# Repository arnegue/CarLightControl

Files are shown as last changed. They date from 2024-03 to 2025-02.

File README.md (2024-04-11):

# CarLightControl
Control and dim (dismounted) carlights with an ESP32 webserver, or via potentiometer.

A friend of mine asked me for a small project to control old taillights from his car. Me, happy that i can solder and program again and willing to help, started doing it. Here it is.

## What's in the code
The code controls 5 lights of one backlight of a car:
* Blinker
* Reverse light
* Brake light
* Running light

Each light is individually dimmable. Blinker is able blink (you don't say).

# Circuit
See  [this diagram](#Simplified) for a simplified circuit. I also made a more professional one with EasyEDA which could be ordered there for a few bugs.

## Easy-EDA
Follow link to [OSHWLab](https://oshwlab.com/frostfreak/carlightcontrol):

## Simplified
Following diagram (nice paint skills, eh?) shows a simplified circuit how every bulb (in this case only one) is connected to the ESP32.

* **12 V**: Power Source for dimming/switching/blinking lamps
* **5 V**: Power Source for ESP32 (depends on your development kit!)
* **3.3 V**: Maximum voltage for ESP32 Input from potentiometer
* **IRF9540N**: P-Channel Mosfet to control each bulb
* **BC547**: NPN-Transistor to toggle IRF9540N
* **250 Ohms potentiometer**: for measuring voltage input
* **1K Ohms resistor**: On ESP32 for safeguarding and current limiting
* **10K Ohms resistor**: Pull up resistor

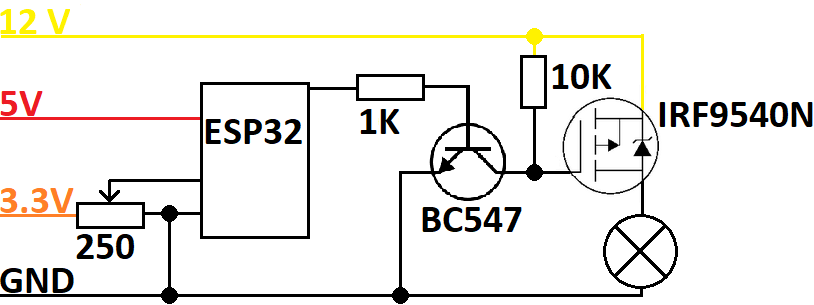
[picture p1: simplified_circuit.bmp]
simplified circuit diagram


Note: I take no guarantee on correctness. I am a programmer, not an electronics engineer ;)

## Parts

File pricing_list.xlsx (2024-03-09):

 | Typ | Name | Anzahl | Einzelpreis | Preis
Platine | Microcontroller | ESP32 WROOM32D | 1 | 8.99 € | 8.99 €
 | Buchse & Stecker | JST 3er | 4 | 0.10 € | 0.40 €
 | Transistor | NPN BC547 | 4 | 0.34 € | 1.36 €
 | Transistor | P-Channel Mosfet IRF9540N | 4 | 0.34 € | 1.36 €
 | Widerstand | Widerstände | 8 | 0.08 € | 0.64 €
 | Buchse & Stecker | JST 2er (Strom) | 1 | 0.10 € | 0.10 €
 | Spannungswandler | MP1584EN | 1 | 1.50 € | 1.50 €
 | Buchse & Stecker | JST 6er (Anschluss zu Lampenbuchse) | 1 | 0.10 € | 0.10 €
 | Kühlkörper | Aluminium Kühlkörper | 4 | 0.36 € | 1.44 €
Gehäusewand | Buchse & Stecker | Lampenbuchse & -Stecker | 1 | 1.50 € | 1.50 €
 | Buchse & Stecker | Strombuchse | 1 | 3.75 € | 3.75 €
 |  | Netzadapter (12V 5A) | 1 | 13.89 € | 13.89 €
Deckel | Potentiometer | Linear Potentiometer 250 Ohm | 4 | 1.78 € | 7.12 €
 | Schalter | Kippschalter 12V | 1 | 2.75 € | 2.75 €
Gehäuse | Gehäuse | ABS Kunststoffgehäuse | 1 | 7.17 € | 7.17 €
 |  |  |  |  | 52.05 €

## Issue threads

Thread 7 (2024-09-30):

Work without WiFi

arnegue, 2024-09-30:
The device won't work without WiFi. That's not necessary

SubFeature:

- Additionally print out own IP when connected
- change hostname

Closed 2025-02-13.

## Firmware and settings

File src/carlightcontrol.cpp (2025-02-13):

#include "wifi_secrets.h"
#include "pwm_switch.hpp"
#include "blinking_pwm_switch.hpp"
#include "switch_web_server.hpp"

#define ENABLE_POTENTIOMETER /* You might want to disable them for testing */

// clang-format off
// Create instances of Lights
//                         Name             PWMPin, PotiPin
PWMSwitch ruecklicht{     "Ruecklicht",     13,     35}; // PWM1
PWMSwitch bremslicht{     "BremsLicht 1",   27,     34}; // PWM2
BlinkingPWMSwitch blinker{"Blinker",        33,     39}; // PWM3
PWMSwitch rueckfahrlicht{ "Bremslicht 2",   32,     36}; // PWM4
// clang-format on

// Add lights to vector
const static std::vector<PWMSwitch *> switches = {
    &ruecklicht,
    &bremslicht,
    &rueckfahrlicht,
    &blinker};

SwitchWebServer web_server(switches, 80);

void CheckWiFiStatus(wl_status_t &previousState)
{
    auto wifiState = WiFiClass::status();
    if (wifiState != WL_CONNECTED)
    {
        Serial.printf("Connecting to WiFi. Current state: %d\n", wifiState);
    }
    else if (wifiState == WL_CONNECTED && previousState != wifiState)
    {
        Serial.printf("Connected to WiFi \"%s\" with IP: ", ssid);
        Serial.println(WiFi.localIP());
        previousState = wifiState;
    }
}

wl_status_t lastWiFiState = WL_DISCONNECTED;

/**
 * @brief Setup routine. Setups Serial, WiFi, Switches and SwitchWebServer
 */
void setup()
{
    Serial.begin(115200);

    // WiFi
    WiFi.begin(ssid, password);
    WiFiClass::setHostname("headlight1");
    CheckWiFiStatus(lastWiFiState);

    // Switches
    for (auto pwm_switch : switches)
    {
        Serial.print("Setting up switch: ");
        Serial.println(pwm_switch->getName());
        pwm_switch->setup();
    }
    Serial.println("Setup switches");

    // Server
    Serial.println("Starting server");
    web_server.begin();
    Serial.println("Started server");
}

/**
 * @brief  Loop which polls wifi state and potentiometer values. If a value changed, override current one (else keep the one either set by previous pwm or from server)
 */
void loop()
{
    CheckWiFiStatus(lastWiFiState);
#ifdef ENABLE_POTENTIOMETER
    for (auto pwm_switch : switches)
    {
        pwm_switch->measurePotentiometerSetValue();
    }
#endif
    delay(100);
}

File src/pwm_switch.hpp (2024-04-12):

#ifndef PWM_SWITCH_H
#define PWM_SWITCH_H

#include <WString.h>
#include <stdint.h>
#include <esp32-hal.h>

/**
 * @brief Class for a PWM-based Switch (Light)
 */
class PWMSwitch
{
public:
    /**
     * @brief Construct a new PWMSwitch object
     *
     * @param pwm_name Name of switch
     * @param pwm_pin Pin to toggle PWM
     * @param potentiometer_pin Pin of potentiometer
     */
    PWMSwitch(const String &pwm_name, uint8_t pwm_pin, uint8_t potentiometer_pin)
        : mName(pwm_name),
          mPWMPin(pwm_pin),
          mPotentiometerPin(potentiometer_pin) {}

    /**
     * @brief Destroy the PWMSwitch object
     */
    virtual ~PWMSwitch() = default;

    /**
     * @brief Return next pwm channel. Only call once per instance!
     *
     * @return next pwm channel
     */
    static uint8_t getNextPWMChannel();

    /**
     * @brief Sets up PWM. Attach timer, set pin and frequencies
     */
    virtual void setup();

    /**
     * @brief Returns name of switch
     *
     * @return Name
     */
    const String &getName() const;

    /**
     * @brief Enables PWM. When switching on, set mDutyCycle to previous set value
     *
     * @param on Boolean to set on (true) or off (false)
     */
    virtual void setOutput(bool on);

    /**
     * @brief Returns if the PWM Switch is powered on
     *
     * @return true if on, false if off
     */
    virtual bool getOutput() const;

    /**
     * @brief Sets duty-cycle. (calculated from given percentage)
     * If given percentage is 0, switch off
     * If given percentage above 0, switch (on) to given value
     *
     * @param percentage Percentage (0-100) to set value
     */
    virtual void setValue(uint8_t percentage);

    /**
     * @brief Returns current duty-cycle in percent
     *
     * @return duty cycle
     */
    uint8_t getValue() const;

    /**
     * @brief Measures potentiometer pin. If value changed over threshold (CHANGE_PERC), set value to pwm
     */
    virtual void measurePotentiometerSetValue();

private:
    static uint8_t mNextFreePWMChannel;              // Internal counter. For each switch a counter
    const String mName;                              // Name for logging
    uint8_t mDutyCycle = 0;                          // Currently set duty-cycle
    const uint8_t mPWMPin;                           // PWM-Pin
    const uint8_t mPWMChannel = getNextPWMChannel(); // PWM channel used for PWM pin

    // PWM-Constants
    static const uint16_t PWM_FREQ = 500;     // Frequency for pwm
    static const uint8_t RESOLUTION_BITS = 8; // Could get up to 16 bit, but we don't need it here
protected:
    bool mOutputEnable = false;           // output enable
    const uint8_t mPotentiometerPin;      // Analog pin for potentiometer
    uint8_t mLastMeasuredChange_perc = 0; // Last measured potentiometer value (to detect changes)

    //  Analog-Constants
    static const uint16_t MAX_VALUE = (1 << RESOLUTION_BITS) - 1;
    static const uint16_t MAX_ANALOG_IN = 0xFFF; // Maximum analog value (12 bit)
    static const uint8_t CHANGE_PERC = 5;        // Avoid oscillation, only trigger if this value differ
};

#endif // PWM_SWITCH_H

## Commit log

2023-03-23 Changed pins, esp somehow doesnt support some for gpio and/or pwm
2023-03-23 Added fritzing-schematic
    [TailLight.fzz]
2023-03-23 Turning PWM off if value is 0
2023-03-27 Split PWM-Switches into files, blinkers now blink individually
2023-03-28 Moved more files
    [CarLightcontrol.fzz, TailLight.fzz]
2023-03-28 Analog in seems to work now with blinker
    [CarLightcontrol.fzz]
2023-03-31 Avoiding potentiometer-change detection on statup
    [blinking_pwm_switch.h]
2023-09-18 Minor Updates, added notes
    [CarLightcontrol.fzz]
2023-09-25 Using IRF9540 instead
    [CarLightcontrol.fzz]
2024-02-13 Added possibility to en/disable pwm via preprocessor
2024-02-13 Update fritzing file
    [CarLightcontrol.fzz]
2024-03-09 Using VSCode with PIO instead of Arduino IDE
    [pricing_list.xlsx]
2024-03-09 Got rid of some sonarlint warnings
2024-03-27 Fixed typo, minor formatting
    [carlightcontrol.cpp]
2024-04-01 Added PWM-comment
2024-04-07 Cleanup of PWM-Switch and Blinking PWM-Switch
2024-04-11 #1 Updated link and image for PCB
    [CarLightcontrol.fzz]
2024-04-12 Using camel-case instead of snake-case
